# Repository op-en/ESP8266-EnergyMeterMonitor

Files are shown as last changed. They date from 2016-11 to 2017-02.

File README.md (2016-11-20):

# ESP8266-EnergyMeterMonitor
This is a project to create an energy visualisation based on an ESP8266 that connects to the LED of a power meter with a phototransistor.

##How to use

###Software

1. Download or compile firmware to your NoceMCU chip with software from: http://nodemcu-build.com. Be sure to check MQTT, SNTP, File, Node, GPIO, RTC time, timer, UART and so on.

2. Flash your firmware with the float version of the firmware. Example: esptool.py -p /dev/cu.wchusbserial1410 write_flash -fm dio -fs 32m 0x00000 nodemcu-master-21-modules-2016-07-11-12-51-01-float.bin 

3. Update the settings (settings.lua) file with you WIFI credentials and meter pulse unit (should be printed on the casing of the electric meter unit). And upload it through the ESPlorer to the NodeMCU

4. Upload all files in the /src directory to the NodeMCU. Save the init file to last.

5. Reboot the NodeMCU and write down the data url printed by the NodeMCU in the ESPlorer console.

###Hardware:

1. Connect a phototransistor to the GND and GPIO5  (situated next to each other) on the NodeMCU using a 2 x female to female dupont cable. Make sure the phototransistor is turned the right way. The short leg with the broad stop piece should be connected to GPIO5 and the long leg to GND.
2. Insert a resistor with a value between 80k and 400k* in serial with the phototransistor.  

*The smaller the resistande the more sensitive the phototransistor will be. A to small value will make the blue led on the NodeMCU to be on all the time instead of just flashing when the electric meter does. A to big value or no resistor at all will make the unit stop detecting pulses when the suroundings are to dark. 

3. 3D print the stl file with the phototransistor holder and push the phototransistor into it. 
4. Cut out some double adhasive tape (the foam type works well) and place around the opening of the phototransistor holder. 
5. Stick the phototransistor holder to the led* on you electric meter and test. 

* Some diod are IR where you cant see the light. There are also different sorts of diods on some meters 2 pair for datacommunication with the meter and 1-2 for flashing the pulses. It usually says kwh or 1000 imp/kwh or something simular next to the correct one.

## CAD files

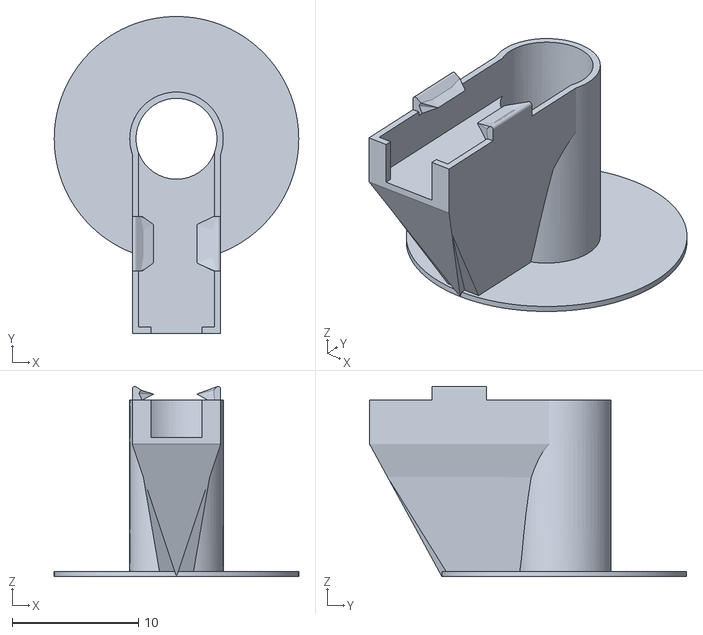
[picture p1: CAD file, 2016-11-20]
casing/Phototransistor holder.stl
19.4 x 25.1 x 15.1

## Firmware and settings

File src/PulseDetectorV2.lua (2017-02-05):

count = 0
low = 0
high = 0
last = 0
prev_sec = 0
prev_usec = 0
pin = 5
before = 0
miss = 0
levelcount = 0
mylevel = false
lastlevel = gpio.read(pin)
ev_before = 0
ev_delta=0
debug=true 

pulsestart = 0
pulseend = 0
pulselength = 0
oldpulsestart = 0
period = 0
count = 0
energy = 0
power = 0
last_power = 0
factor = 3600000/EMM_pulse_unit -- 1000 imp/kWh. 1W will give us a period of 1 pulse per hour. I.e. P = 360000 ms  
min_pulselenght = EMM_min_pulselenght
max_pulselenght = EMM_max_pulselenght
min_change = 0
heartbeat = 10
oldtime = 0
oldenergy = 0
time=0

gpio.mode(4, gpio.OUTPUT)

gpio.mode(pin, gpio.INPUT,gpio.PULLUP)

rtctime.set(1468431267)

function checklevel(n)

    c = 0
    for i=1,n do
            c = c + gpio.read(pin)
        end
    return c
end
 

gpio.trig(pin, "both", function(level)

    levelcount = checklevel(10)

    last = last + 1

    sec, usec = rtctime.get()
    time = sec + usec/1000000
    now = tmr.now()/1000
    
    delta = now - before
    ev_delta = now - ev_before
    ev_before = now

    if levelcount == 10 then
        mylevel = gpio.HIGH
        gpio.write(4,gpio.HIGH)
    else
        mylevel = gpio.LOW
        gpio.write(4,gpio.LOW)
    end 

    log("" .. now .. " : " .. mylevel .. " : " .. delta)

    --if mylevel = level then
    --    print("Level error")
    --end
    idelta = math.floor(delta)

    if mylevel == lastlevel then
        levelcheck2  = checklevel(10)
        
        msg = "Conflict: ML" .. mylevel .. " L" .. level .. " CL" .. levelcheck2 .. " LL" .. lastlevel

        log(msg)
        
        if (lastlevel == gpio.HIGH and mylevel == gpio.HIGH and levelcheck2 == 10) then
            log("Ignore")
            return
        end
        
        if mylevel ~= level or (levelcheck2 == 10 and lastlevel == gpio.LOW) then
            --print("Conflict: ML" .. mylevel .. " L" .. level .. " CL" .. checklevel(10) .. " LL" .. lastlevel )
            --print("Fixing!")
            log("Fix1")
            
            if lastlevel == gpio.HIGH then
                mylevel = gpio.LOW
            else
                mylevel = gpio.HIGH
            end
        end

       
        

    end

    before = now
    lastlevel = mylevel
 
    --******************************************** 
    -- Energy messages
     if (mylevel == gpio.HIGH) then
        pulseend = now
        pulselenght = pulseend - pulsestart

        --Handle wraps of timer
        if pulselenght < 0 then
            pulselenght = pulselength + 2147483.648
        end
        
        count = count + 1

        period = pulsestart - oldpulsestart

        --Handle wraps of timer
        if period < 0 then
            period = period + 2147483.648
        end

        oldpulsestart = pulsestart

        log(" ")
        ioevent()

        if pulselenght > min_pulselenght and pulselenght < max_pulselenght then
            energy = energy + 1
            power = factor/period
            
            if (math.abs(power-last_power) > min_change) then
                meterevent()
            end

        end
     else
        
        --period = now - pulsestart 
        pulsestart = now
       
     end
 

  end)

 
 
  function ioevent()

    msg = "{"
    
    --If we have a time sync add current time.
    if (synced) then
        msg = msg ..  "\"time\":".. sec .. "." .. math.floor(usec/1000) .. ","
    end
    msg = msg .. "\"count\":" .. count

    --If we have a previous pulse att period.
    
    msg = msg .. ", \"period\":".. period
    

    if (sec > 0) then
       msg = msg .. ", \"pulse\":".. pulselenght
    end

    msg = msg .."}"


    
    if connected then
        m:publish(cmd_ch .. "/ioevent",msg,0,1)
    end
  end

  function meterevent()  

    msg2 = "{"


    if (synced) then
        msg2 = msg2 ..  "\"time\":".. oldtime .. ","
    end
    msg2 = msg2 .. "\"energy\":" .. oldenergy


    --If we have a previous pulse att period.
    if (delta > 0) then
       msg2 = msg2 .. ",\"power\":".. power
    end
    msg2 = msg2 .."}"

    oldtime = time
    oldenergy = energy

    
    m:publish(cmd_ch .. "/meterevent",msg2,0,1)
  end

  

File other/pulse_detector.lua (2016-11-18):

print("Starting pulse detector script")


--Globals
count = 0
prev_sec = 0
prev_usec = 0
connected = false
sec = 0
usec = 0
energy = 0
valid = false
pin = 4
tsyncing = false
synced = false

 

--Just to get pulse lenght to work
rtctime.set(1468431267)
 

function synctime()
    if (tsyncing == false) then
        tsyncing = true
        sntp.sync('ntp1.sptime.se',
          function(sec,usec,server)
            tsyncing = false
            print('Time synced: ' .. sec .. "." .. usec)
            synced = true
            --resync time every hour.
            tmr.alarm(0, 3600000, tmr.ALARM_AUTO, synctime)
          end, 
          function()
           tsyncing = false
           print('Time sync failed!')
           synced = false
            --retry time every 30sec.
            synctime()
            --tmr.alarm(0, 10000, tmr.ALARM_AUTO, synctime)
          end
        )
    end
end


print("Opening pin " .. pin .. " for pulse detection")

gpio.mode(pin, gpio.INPUT,gpio.PULLUP)
gpio.trig(pin, "both", function(level)
gpio.mode(3, gpio.OUTPUT)
gpio.write(3,0)

 if (level == gpio.LOW) then

    count = count + 1

    sec, usec = rtctime.get()

    while (gpio.read(4) == gpio.LOW) do

    end 

    hsec, husec = rtctime.get()

    pulselength =  husec-usec + (hsec - sec) * 1000000

    delta = (sec-prev_sec) * 1000 + (usec - prev_usec)/1000


    if (pulselength > 400) and (pulselength < 5000) and (delta > 180) then
        energy = energy + 1
        valid = true
    else
        valid = false
    end


    --print(sec,prev_sec,usec,prev_usec)

    --Create message.
    msg = "{"

    --If we have a time sync add current time.
    if (synced) then
        msg = msg ..  "time:".. sec .. "." .. usec/1000 .. ","
    end
    msg = msg .. "count:" .. count

    --If we have a previous pulse att period.
    if (prev_sec > 0) then
       msg = msg .. ", period:".. delta
    end

    if (sec > 0) then
       msg = msg .. ", pulse:".. pulselength
    end

    msg = msg .."}"


    --Create message 2.
    msg2 = "{"

    if (synced) then
        msg2 = msg2 ..  "time:".. sec .. "." .. usec/1000 .. ","
    end
    msg2 = msg2 .. "energy:" .. energy


    --If we have a previous pulse att period.
    if (delta > 0) then
       msg2 = msg2 .. ",power:".. 3600000/delta
    end
    msg2 = msg2 .."}"

    
    if (connected) then
        m:publish("mainmeter/ioevent",msg,0,0)

        if (valid) then
            m:publish("mainmeter/meterevent",msg2,0,0)
        end
    end

    print("     " .. msg)

    if (valid) then
        print(msg2)
    end

    prev_sec = sec
    prev_usec = usec

 end

  end)





m = mqtt.Client("pulse_detector", 30)


m:on("connect", function(con)
    print ("MQTT connected")
    connected = true

end)
m:on("offline", function(con)

    print ("MQTT disconnected")
    connected = false
    MQTTConnect()
end)

-- on receive message
m:on("message", function(conn, topic, data)
  print(topic .. ":" )
  if data ~= nil then
    print(data)
  end
end)
 
cmd_ch = "esp/" .. wifi.sta.getmac() .. ""
m:lwt(cmd_ch, "MCU offline", 0, 1)
 
 
function MQTTConnect()
   
    --m:close()

    if connected == true then
        return
    end 
    
    m:connect("192.168.1.170", 1883, 0, function(conn)
      print("MQTT connected")
      connected = true
      -- subscribe topic with qos = 0
      m:subscribe(cmd_ch .. "/cmd",0, function(conn)
        -- publish a message with data = my_message, QoS = 0, retain = 0
        m:publish(cmd_ch,"MCU online",0,1, function(conn)
          --print("sent")
        end)
      end)
     end)
 end

 wifi.sta.eventMonReg(wifi.STA_GOTIP, function() 
 
    print("STATION_GOT_IP") 
    MQTTConnect()
 end)
 


print("Syncing time")
synctime()
print("Connecting to MQTT")
MQTTConnect()

--MQTTConnect()

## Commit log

2016-11-20 Fixed power value being ahead
    [PulseDetectorV2.lua]
2016-11-20 Fixed debug prints
